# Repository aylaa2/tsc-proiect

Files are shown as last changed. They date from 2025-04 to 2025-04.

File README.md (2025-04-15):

# OpenBook – Open-Source E-Book Reader

OpenBook este un e-book reader open-source, low-cost, dezvoltat în cadrul proiectului TSC.  
Dispozitivul este construit pe baza microcontrolerului **ESP32-C6** și integrează funcționalități avansate de afișare, comunicație și consum redus de energie, fiind pregătit pentru producție în masă.

---

##  Diagrama Bloc

Diagrama bloc care ilustrează conexiunile dintre toate componentele:

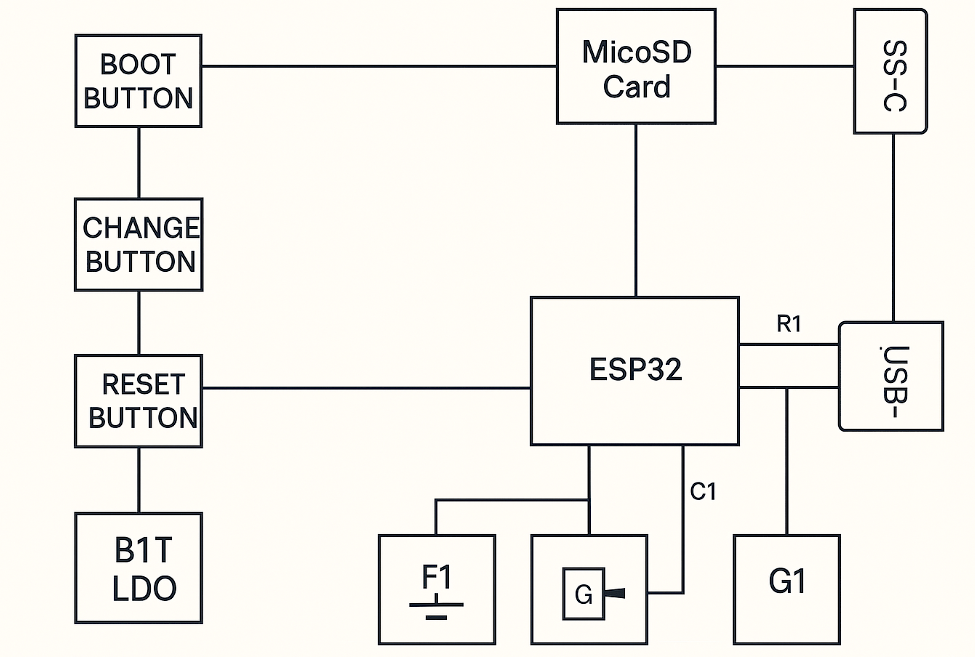
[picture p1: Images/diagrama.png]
Diagrama Bloc


---

##  BOM – Bill of Materials

# Bill of Materials (BOM)

| Package | Parts | Datasheet | 
|:---|:---|:---|
| ADAFRUIT_CHIP-LED0603 | CHG_LED | [Link](https://www.snapeda.com/parts/KP-1608SURCK/Kingbright/view-part/?ref=search&t=LED%200603) | 
| SJ | SJ1 | [Link](https://grabcad.com/library/solder-jumpers-1) |
| ESP32_WROVER_EAGLE-LTSPICE_R0402 | R1_PWRUSB, R1, R1_PINH1, R2-PINH, R2-PINH1, R5, R6, R7, R8, R9, R10, R_BOOT, R_CL1, R_RESET, R3, R1_PINH, R4, R_CHANGE, R_CAPACITOR, R2, R1_BAT, R2_BAT, R2_USB, R2_USB1 | [Link](https://componentsearchengine.com/part-view/R0402%201%25%20100%20K%20(RC0402FR-07100KL)/YAGEO) | 
| ESP32_WROVER_EAGLE-LTSPICE_C0402 | C1, C2, C4_USB, C6, C8, C9, C10, C_DELAY, EPD_C5, EPD_C1, EPD_C2, EPD_C6, EPD_C7, EPD_C8, EPD_C9, EPD_C10, EPD_C11, EPD_C12, C7, C5, C4, C1_BAT, C1_BAT1, C1_BAT2, C2_BAT, C5_USB | [Link](https://componentsearchengine.com/part-view/CC0402MRX5R5BB106/YAGEO) | 
| RCL_CT3528 | C3 | [Link](https://stud33302.autodesk360.com/g/shares/SH30dd5QT870c25f12fc6065d74bcaa3bf24) |
| 112ATAARR03ATTEND | J4 | [Link](Link) |
| ESP32_WROVER_SPARKFUN-DISCRETESEMI_SOT23-3 | Q1, Q2 | [Link](https://ro.mouser.com/ProductDetail/Microchip-Technology/MCP73831T-5ACI-OT?qs=hH%252BOa0VZEiAcgAcEkuamXg%3D%3D) |
| SOT95P280X125-5N | IC1 | [Link](https://componentsearchengine.com/part-view/BD5229G-TR/ROHM%20Semiconductor) |
| MYBUTTON | BOOT_BUTTON, CHANGE_BUTTON, RESET_BUTTON | [Link](https://industry.panasonic.com/global/en/products/control/switch/light-touch/number/evqpuj02k) |
| CAPCP3225X100N | C10_SUPERCAP | [Link](https://www.snapeda.com/parts/CPH3225A/Seiko+Instruments/view-part/?ref=eda) | 
| SOIC127P1032X265-16N | U3 | [Link](https://www.snapeda.com/parts/DS3231SN%23/Analog+Devices/view-part/?ref=eda) | 
| XCVR_ESP32-C6-WROOM-1-N8 | U2 | [Link](https://www.snapeda.com/parts/ESP32-C6-WROOM-1-N8/Espressif+Systems/view-part/?ref=eda) | 
| ESP32C6_VARISTOR_CT/CN1812 | PFMF.050.1 | [Link](Link) | 
| ESP32_WROVER_AVX---SD0805S020S1R0_AVX_SD0805S020S1R0_0 | D2, D7 | [Link](https://eu.mouser.com/ProductDetail/KYOCERA-AVX/SD0805S020S1R0?qs=jCA%252BPfw4LHbpkAoSnwrdjw%3D%3D) | 
| ESP32_WROVER_BME680_PSON80P300X300X100-8N | SENSOR2 | [Link](https://www.snapeda.com/parts/BME680/Bosch/view-part/?welcome=home) | 
| ESP32_WROVER_SPARKFUN-IC-POWER_SOT23-5 | U0 | [Link](Link) |
| FH34SRJ24S05SH99 | J1 | [Link](Link) | 
| SON50P200X200X80-9N | U4 | [Link](https://www.snapeda.com/parts/MAX17048G+T10/Analog+Devices/view-part/?ref=eda) | 
| SOD3716X135N | D3, D4, D5 | [Link](Lihttps://eu.mouser.com/ProductDetail/KYOCERA-AVX/SD0805S020S1R0?qs=jCA%252BPfw4LHbpkAoSnwrdjw%3D%3Dnk) | 
| DIOC1608X36N | D6, D8, D9, D10, D11, D12 | [Link](https://www.snapeda.com/parts/PGB1010603MR/Littelfuse/view-part/?ref=eda) | 
| JST04_1MM_RA | J3 | [Link](https://componentsearchengine.com/part-view/USB4110-GF-A/GCT%20(GLOBAL%20CONNECTOR%20TECHNOLOGY)) | 
| SAMACSYS_PARTS_USB4110GFA | J2 | [Link](https://componentsearchengine.com/part-view/USB4110-GF-A/GCT%20(GLOBAL%20CONNECTOR%20TECHNOLOGY)) | 
| SOT95P280X145-6N | D1 | [Link](https://www.snapeda.com/parts/USBLC6-2SC6Y/STMicroelectronics/view-part/?ref=eda) | 
| SON127P600X800X80-9N | U1 | [Link](https://www.snapeda.com/parts/W25Q512JVEIQ/Winbond+Electronics/view-part/?ref=eda) | 
| SOT95P280X120-5N | IC4 | [Link](https://www.snapeda.com/parts/W25Q512JVEIQ/Winbond+Electronics/view-part/?ref=eda) |

##  Descriere Hardware

OpenBook folosește următoarele module și componente:

- **ESP32-C6-WROOM-1-N8** – Microcontroller principal cu conectivitate WiFi 6, BLE și Zigbee.
- **W25Q512JVEIQ** – Memorie Flash SPI pentru stocarea datelor.
- **MAX17048** – Fuel Gauge pentru monitorizarea nivelului de încărcare a bateriei.
- **MCP73831** – Circuit de încărcare Li-Ion prin USB Type-C.
- **DS3231** – Ceas de timp real cu acuratețe ridicată.
- **BME680** – Senzor ambiental pentru calitatea aerului, temperatură și umiditate.
- **CPH3225A** – Supercapacitor pentru backup RTC.
- **USB4110-GF-A** – Conector USB Type-C pentru alimentare și comunicație.

**Specificații de comunicație și interfețe:**
- **I2C**: DS3231 (RTC), BME680 (senzor ambiental)
- **SPI**: W25Q512JVEIQ (memorie Flash externă)
- **I2C/SPI**: Ecran E-Paper
- **Fuel Gauge (MAX17048)**: comunicație prin I2C
- **USB**: Alimentare și încărcare prin MCP73831 + conector USB-C

**Calcul de consum de energie:**
- Dispozitivul intră în mod Deep Sleep ESP32 pentru a minimiza consumul (~20 µA).
- Fuel Gauge optimizează încărcarea/descărcarea bateriei pentru o autonomie maximă.

---

##  Pini ESP32-C6 

Mai jos este un rezumat al pinilor folosiți pe microcontroller, cu funcțiile și componenta asociată:

| GPIO  | Componentă | Funcție |
|---|---|---|
| EN | Buton Reset | Reset hardware |
| IO0 | RTC | INT_RTC (interupt RTC) |
| IO1 | RTC | 32KHz output |
| IO2 | SD Card | MISO |
| IO3 | E-paper Display | EPD_BUSY |
| IO4 | SD Card | SS_SD (chip select) |
| IO5 | E-paper Display | EPD_DC |
| IO6 | SPI Shared | SCK |
| IO7 | SPI Shared | MOSI |
| IO8 | GPIO | Utilizare generica |
| IO9 | Boot Button | Mod programare |
| IO10  | E-paper Display | EPD_CS |
| IO11  | NOR Flash | FLASH_CS |
| IO12  | USB Interface | USB_D- |
| IO13  | USB Interface | USB_D+ |
| IO15  | Buton Change | Detectare schimbare |
| IO16  | UART | TX (debug serial) |
| IO17  | UART | RX (debug serial) |
| IO18  | RTC | RTC_RST |
| IO19  | MAX17048 | I2C_PW (alimentare I2C) |
| IO20  | E-paper Display | EPD_3V3_C (power control) |
| IO21  | I2C Shared | SDA |
| IO22  | I2C Shared | SCL |
| IO23  | E-paper Display | EPD_RST |

---

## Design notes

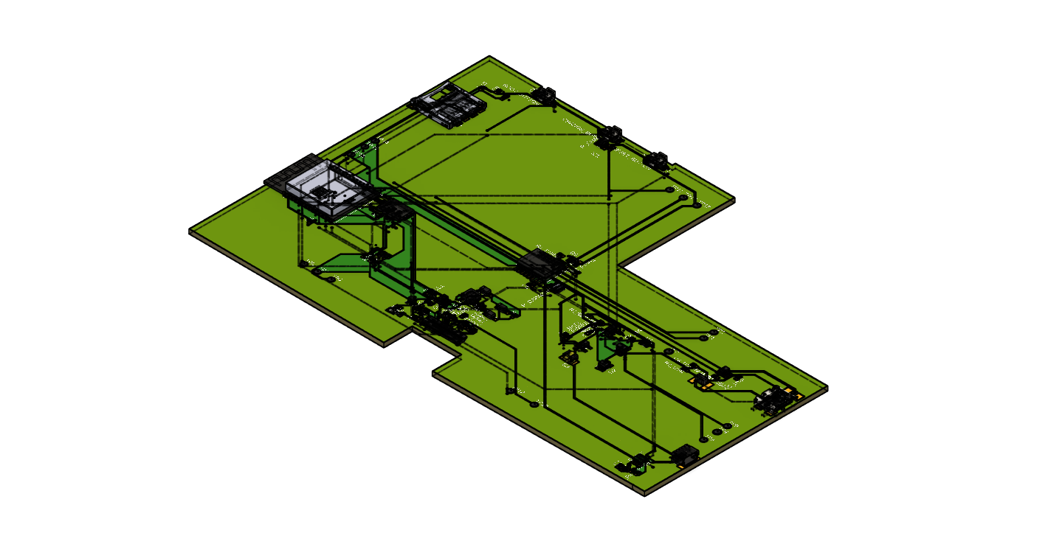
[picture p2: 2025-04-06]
Images/pleaca3d.png

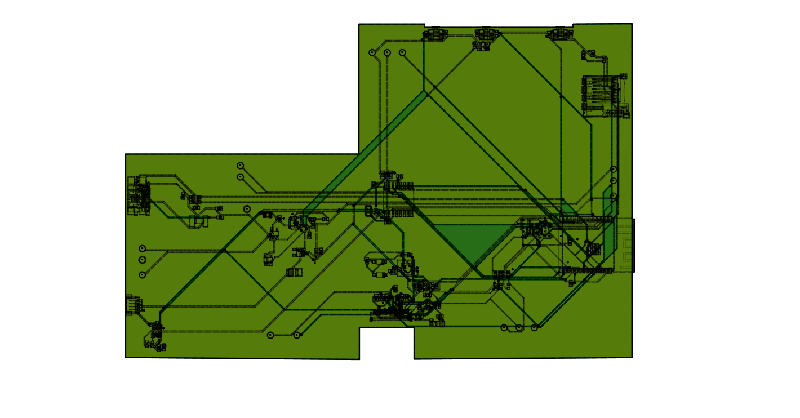
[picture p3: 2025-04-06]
Images/temabottom.png

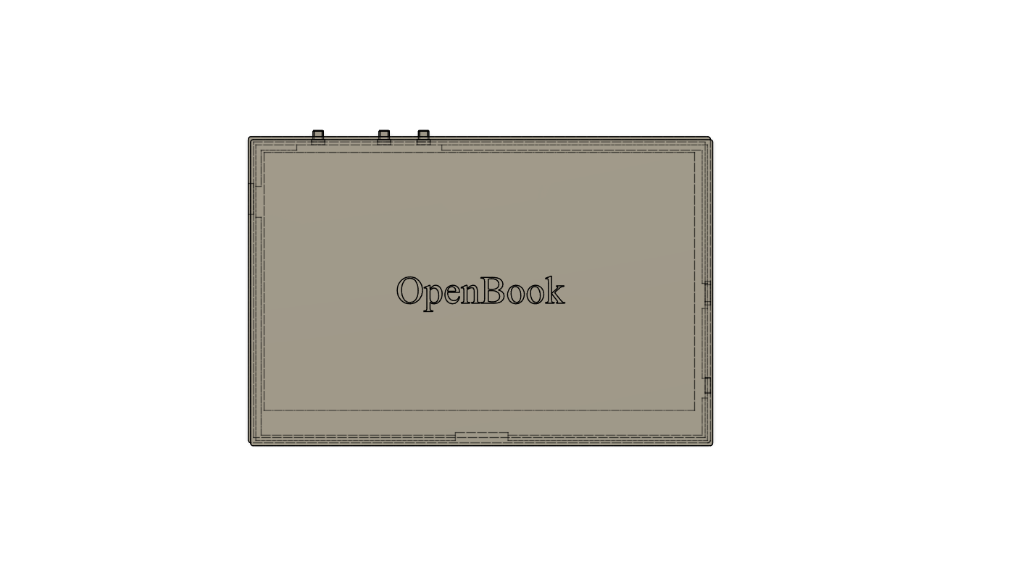
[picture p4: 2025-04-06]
Images/OpenBook Enclosure .png

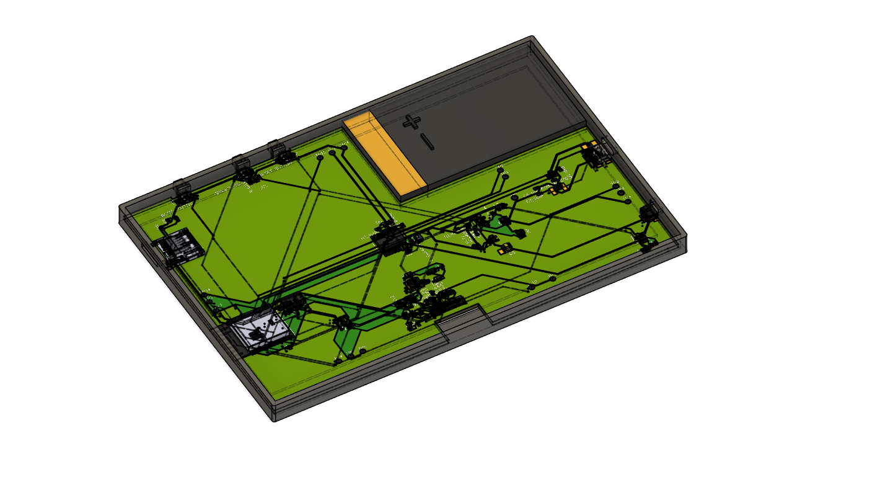
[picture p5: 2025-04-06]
Images/OpenBook Enclosuretop.png

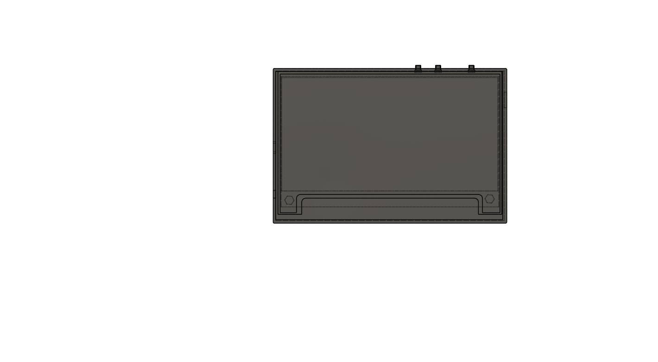
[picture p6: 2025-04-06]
Images/OpenBook Enclosure final v1.png

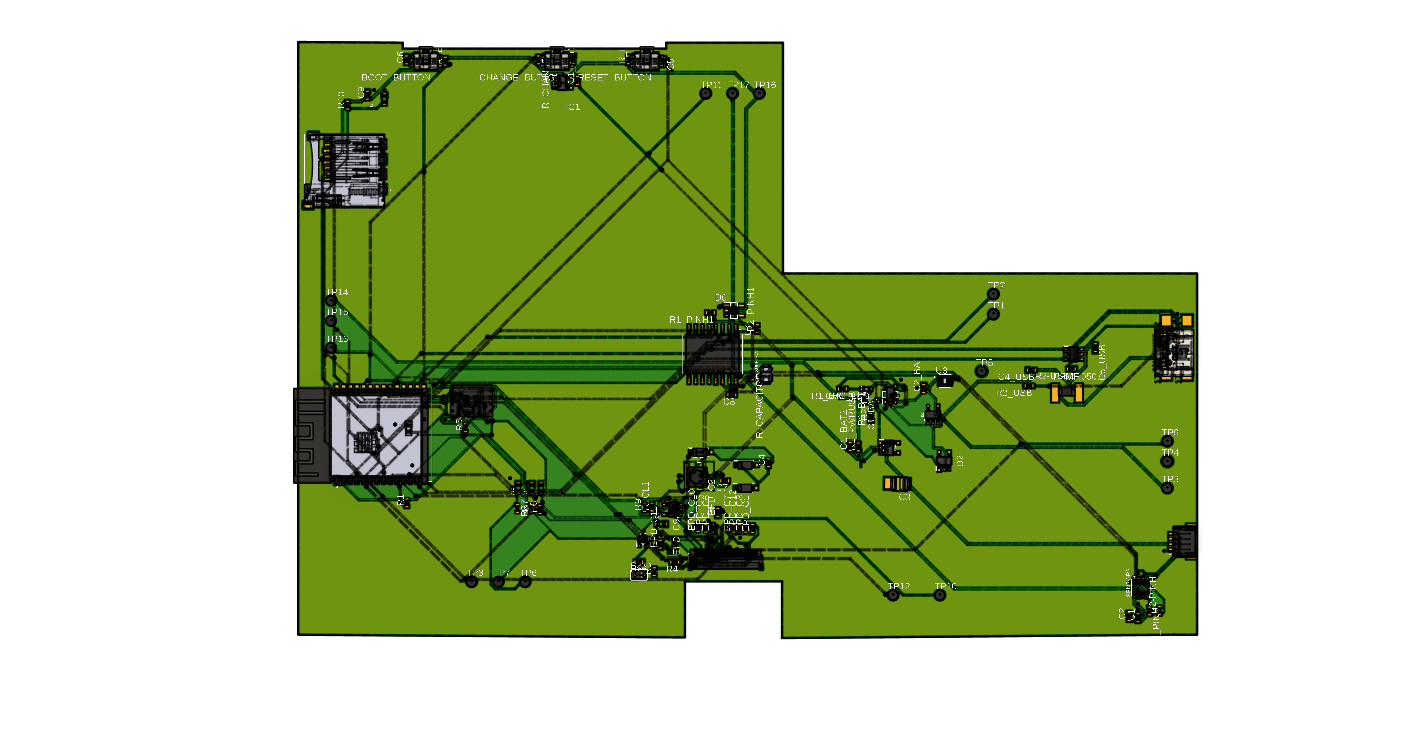
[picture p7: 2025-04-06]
Images/tema.png

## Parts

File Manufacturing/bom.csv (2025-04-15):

Qty | Value | Device | Package | Parts | Description | ARROW_PART_NUMBER | ARROW_PRICE-STOCK | AVAILABILITY | CENTROID_NOT_SPECIFIED | CHECK_PRICES | COPYRIGHT | DATASHEET | DESCRIPTION | DIGIKEY_DESCRIPTION | DIGIKEY_PART_NUMBER | HEIGHT | LEAD_FREE | MANUFACTURER_NAME | MANUFACTURER_PART_NUMBER | MF | MFR_NAME | MOUSER_PART_NUMBER | MOUSER_PRICE-STOCK | MOUSER_TESTING_PART_NUMBER | MOUSER_TESTING_PRICE-STOCK | MP | MPN | PACKAGE | POPULARITY | PREFIX | PRICE | PROD_ID | PURCHASE-URL | ROHS | SNAPEDA_LINK | SPICEMODEL | SPICEPREFIX | TEMPERATURE_RANGE_HIGH | TEMPERATURE_RANGE_LOW | TP_SIGNAL_NAME | VALUE
1 |  | ADAFRUIT_LEDCHIP-LED0603 | ADAFRUIT_CHIP-LED0603 | CHG_LED | LED
1 |  | SJ | SJ | SJ1 | SMD solder JUMPER |  |  |  |  |  |  |  |  |  |  |  |  |  |  |  |  |  |  |  |  |  |  |  | 3
1 | 0.47 | ESP32_WROVER_EAGLE-LTSPICE_RR0402 | ESP32_WROVER_EAGLE-LTSPICE_R0402 | R3 | RESISTOR, European symbol |  |  |  |  |  |  |  |  |  |  |  |  |  |  |  |  |  |  |  |  |  |  |  |  |  |  |  |  |  |  | NONE | R
1 | 100K | ESP32_WROVER_EAGLE-LTSPICE_RR0402 | ESP32_WROVER_EAGLE-LTSPICE_R0402 | R1_PWRUSB | RESISTOR, European symbol |  |  |  |  |  |  |  |  |  |  |  |  |  |  |  |  |  |  |  |  |  |  |  |  |  |  |  |  |  |  | NONE | R
6 | 100nF | EAGLE-LTSPICE_CC0402 | ESP32_WROVER_EAGLE-LTSPICE_C0402 | C1, C2, C6, C8, C9, C10 | CAPACITOR, European symbol |  |  |  |  |  |  |  |  |  |  |  |  |  |  |  |  |  |  |  |  |  |  |  |  |  |  |  |  |  |  | NONE | C
1 | 100nF | ESP32_WROVER_EAGLE-LTSPICE_CC0402 | ESP32_WROVER_EAGLE-LTSPICE_C0402 | C4_USB | CAPACITOR, European symbol |  |  |  |  |  |  |  |  |  |  |  |  |  |  |  |  |  |  |  |  |  |  |  |  |  |  |  |  |  |  | NONE | C
1 | 100uF TANT | RCL_CPOL-EUCT3528 | RCL_CT3528 | C3 | POLARIZED CAPACITOR, European symbol |  |  |  |  |  |  |  |  |  |  |  |  |  |  |  |  |  |  |  |  |  |  |  | 0 |  |  |  |  |  |  |  | C
13 | 10K | ESP32_WROVER_EAGLE-LTSPICE_RR0402 | ESP32_WROVER_EAGLE-LTSPICE_R0402 | R1, R1_PINH, R1_PINH1, R2-PINH, R2_PINH1, R4, R5, R6, R7, R8, R9, R10, R_CL1 | RESISTOR, European symbol |  |  |  |  |  |  |  |  |  |  |  |  |  |  |  |  |  |  |  |  |  |  |  |  |  |  |  |  |  |  | NONE | R
3 | 10k | ESP32_WROVER_EAGLE-LTSPICE_RR0402 | ESP32_WROVER_EAGLE-LTSPICE_R0402 | R_BOOT, R_CHANGE, R_RESET | RESISTOR, European symbol |  |  |  |  |  |  |  |  |  |  |  |  |  |  |  |  |  |  |  |  |  |  |  |  |  |  |  |  |  |  | NONE | R
1 | 10uF | EAGLE-LTSPICE_CC0402 | ESP32_WROVER_EAGLE-LTSPICE_C0402 | C7 | CAPACITOR, European symbol |  |  |  |  |  |  |  |  |  |  |  |  |  |  |  |  |  |  |  |  |  |  |  |  |  |  |  |  |  |  | NONE | C
1 | 112A-TAAR-R03_ATTEND | 112A-TAAR-R03_ATTEND | 112ATAARR03ATTEND | J2 | Micro SD Card Socket, Push-Push Type, Top Mount, SMT, H=1.83mm, 10u |  |  |  |  |  |  |  | Micro SD Card Socket | Push-Push Type | Top Mount | SMT | H=1.83mm | 10u |  |  | 1.9mm |  | ATTEND | 112A-TAAR-R03 ATTEND
1 | 15 | ESP32_WROVER_EAGLE-LTSPICE_RR0402 | ESP32_WROVER_EAGLE-LTSPICE_R0402 | R_CAPACITOR | RESISTOR, European symbol |  |  |  |  |  |  |  |  |  |  |  |  |  |  |  |  |  |  |  |  |  |  |  |  |  |  |  |  |  |  | NONE | R
1 | 1uF | EAGLE-LTSPICE_CC0402 | ESP32_WROVER_EAGLE-LTSPICE_C0402 | C5 | CAPACITOR, European symbol |  |  |  |  |  |  |  |  |  |  |  |  |  |  |  |  |  |  |  |  |  |  |  |  |  |  |  |  |  |  | NONE | C
10 | 1uF/50V | EAGLE-LTSPICE_CC0402 | ESP32_WROVER_EAGLE-LTSPICE_C0402 | EPD_C1, EPD_C2, EPD_C5, EPD_C6, EPD_C7, EPD_C8, EPD_C9, EPD_C10, EPD_C11, EPD_C12 | CAPACITOR, European symbol |  |  |  |  |  |  |  |  |  |  |  |  |  |  |  |  |  |  |  |  |  |  |  |  |  |  |  |  |  |  | NONE | C
1 | 2.2 | ESP32_WROVER_EAGLE-LTSPICE_RR0402 | ESP32_WROVER_EAGLE-LTSPICE_R0402 | R2 | RESISTOR, European symbol |  |  |  |  |  |  |  |  |  |  |  |  |  |  |  |  |  |  |  |  |  |  |  |  |  |  |  |  |  |  | NONE | R
1 | 200 | ESP32_WROVER_EAGLE-LTSPICE_RR0402 | ESP32_WROVER_EAGLE-LTSPICE_R0402 | R1_BAT | RESISTOR, European symbol |  |  |  |  |  |  |  |  |  |  |  |  |  |  |  |  |  |  |  |  |  |  |  |  |  |  |  |  |  |  | NONE | R
2 | 20V/4.2A/52mO/1.4W | ESP32_WROVER_SPARKFUN-DISCRETESEMI_MOSFET_PCH-DMG2305UX-7 | ESP32_WROVER_SPARKFUN-IC-POWER_SOT23-5 | Q1, Q2 | P-channel MOSFETs |  |  |  |  |  |  |  |  |  |  |  |  |  |  |  |  |  |  |  |  |  |  |  |  |  |  | TRAN-14388 |  |  |  |  |  |  |  |  | 20V/4.2A/52mO/1.4W
1 | 2K | ESP32_WROVER_EAGLE-LTSPICE_RR0402 | ESP32_WROVER_EAGLE-LTSPICE_R0402 | R2_BAT | RESISTOR, European symbol |  |  |  |  |  |  |  |  |  |  |  |  |  |  |  |  |  |  |  |  |  |  |  |  |  |  |  |  |  |  | NONE | R
1 | 4,7uF | EAGLE-LTSPICE_CC0402 | ESP32_WROVER_EAGLE-LTSPICE_C0402 | C1_BAT2 | CAPACITOR, European symbol |  |  |  |  |  |  |  |  |  |  |  |  |  |  |  |  |  |  |  |  |  |  |  |  |  |  |  |  |  |  | NONE | C
2 | 4.7uF | EAGLE-LTSPICE_CC0402 | ESP32_WROVER_EAGLE-LTSPICE_C0402 | C1_BAT, C1_BAT1 | CAPACITOR, European symbol |  |  |  |  |  |  |  |  |  |  |  |  |  |  |  |  |  |  |  |  |  |  |  |  |  |  |  |  |  |  | NONE | C
2 | 4.7uF | ESP32_WROVER_EAGLE-LTSPICE_CC0402 | ESP32_WROVER_EAGLE-LTSPICE_C0402 | C2_BAT, C5_USB | CAPACITOR, European symbol |  |  |  |  |  |  |  |  |  |  |  |  |  |  |  |  |  |  |  |  |  |  |  |  |  |  |  |  |  |  | NONE | C
1 | 4.7uF/25V | EAGLE-LTSPICE_CC0402 | ESP32_WROVER_EAGLE-LTSPICE_C0402 | C4 | CAPACITOR, European symbol |  |  |  |  |  |  |  |  |  |  |  |  |  |  |  |  |  |  |  |  |  |  |  |  |  |  |  |  |  |  | NONE | C
1 | 5K1 | ESP32_WROVER_EAGLE-LTSPICE_RR0402 | ESP32_WROVER_EAGLE-LTSPICE_R0402 | R2_USB | RESISTOR, European symbol |  |  |  |  |  |  |  |  |  |  |  |  |  |  |  |  |  |  |  |  |  |  |  |  |  |  |  |  |  |  | NONE | R
1 | 5k1 | ESP32_WROVER_EAGLE-LTSPICE_RR0402 | ESP32_WROVER_EAGLE-LTSPICE_R0402 | R2-USB1 | RESISTOR, European symbol |  |  |  |  |  |  |  |  |  |  |  |  |  |  |  |  |  |  |  |  |  |  |  |  |  |  |  |  |  |  | NONE | R
1 | 68uH | 744043680IND_4828-WE-TPC_WRE | IND_4828-WE-TPC_WRE | L1 |  |  |  |  |  |  | Copyright (C) 2024 Ultra Librarian. All rights reserved. |  |  |  |  |  |  |  | 744043680 |  | Wurth Electronics
1 | BD5229G-TR | BD5229G-TR | SOT95P280X120-5N | IC2 | Voltage Detector with Adjustable Delay Time: CMOS processes are utilized to develop high precision, low current consumption CMOS reset ICs that allow arbitrary setting of the delay time. The extensive lineup includes both Nch Open Drain and CMOS output types in a wide range of detection voltages (from 2.3V to 6.0V, in 0.1V steps), enabling selection of the ideal solution based on customer requirements. In addition, the entire series is of course both lead-free and RoHS-compliant. |  |  |  |  |  |  |  | Voltage Detector with Adjustable Delay Time: CMOS processes are utilized to develop high precision | low current consumption CMOS reset ICs that allow arbitrary setting of the delay time. The extensive lineup includes both Nch Open Drain and CMOS output types in a wide range of detection voltages (from 2.3V to 6.0V | in 0.1V steps) | enabling selection of the ideal solution based on customer requirements. In addition | the entire series is of course both lead-free and RoHS-compliant. |  |  | 1.25mm |  | ROHM Semiconductor | BD5229G-TR |  |  | 755-BD5229G-TR | https://www.mouser.co.uk/ProductDetail/ROHM-Semiconductor/BD5229G-TR?qs=4kLU8WoGk0vvnhrrYwdszw%3D%3D
3 | BUTTON_CUSYOMV1 | BUTTON_CUSYOMV1 | MYBUTTON | BOOT_BUTTON, CHANGE_BUTTON, RESET_BUTTON
1 | CPH3225A | CPH3225A | CAPCP3225X100N | C10_SUPERCAP | Cap 0.011F 3.3V 1210 Flat Check availability |  |  | Not in stock |  | https://www.snapeda.com/parts/CPH3225A/Seiko+Instruments/view-part/?ref=eda |  |  | 11 mF (EDLC) Supercapacitor 3.3 V 1210 (3225 Metric) - - |  |  |  |  |  |  | Seiko Instruments |  |  |  |  |  | CPH3225A |  | 1210 Seiko |  |  | None |  | https://www.snapeda.com/api/url_track_click_mouser/?unipart_id=562593&manufacturer=Seiko Instruments&part_name=CPH3225A&search_term=None |  | https://www.snapeda.com/parts/CPH3225A/Seiko+Instruments/view-part/?ref=snap
1 | DS3231SN# | DS3231SN# | SOIC127P1032X265-16N | U4 | Real Time Clock Serial 16-Pin SOIC W T/R Check availability |  |  | In Stock |  | https://www.snapeda.com/parts/DS3231SN%23/Analog+Devices/view-part/?ref=eda |  |  | Extremely Accurate I²C-Integrated RTC/TCXO/Crystal |  |  |  |  |  |  | Analog Devices |  |  |  |  |  | DS3231SN# |  | SOIC-16 Maxim |  |  | None |  | https://www.snapeda.com/api/url_track_click_mouser/?unipart_id=99048&manufacturer=Analog Devices&part_name=DS3231SN#&search_term=None |  | https://www.snapeda.com/parts/DS3231SN%23/Analog+Devices/view-part/?ref=snap
1 | ESP32-C6-WROOM-1-N8 | ESP32-C6-WROOM-1-N8 | XCVR_ESP32-C6-WROOM-1-N8 | U2 | Check availability |  |  | In Stock |  | https://www.snapeda.com/parts/ESP32-C6-WROOM-1-N8/Espressif+Systems/view-part/?ref=eda |  |  | Multiprotocol Modules ESP32-C6 module | Wi-Fi 6 in 2.4 GHz band | Bluetooth 5 | Zigbee 3.0 and Thread. ESP34-WROOM Compatible - ENGINEERING SAMPLE |  |  |  |  |  |  | Espressif Systems |  |  |  |  |  | ESP32-C6-WROOM-1-N8 |  | None |  |  | None |  |  |  | https://www.snapeda.com/parts/ESP32-C6-WROOM-1-N8/Espressif+Systems/view-part/?ref=snap
1 | ESP32C6_VARISTORCN1812 | ESP32C6_VARISTORCN1812 | ESP32C6_VARISTOR_CT/CN1812 | PFMF.050.1 | VARISTOR |  |  |  |  |  |  |  |  |  |  |  |  |  |  |  |  |  |  |  |  |  |  |  | 0
2 | ESP32_WROVER_AVX---SD0805S020S1R0_AVX_SD0805S020S1R0_0_0AVX_SD0805S020S1R0_0_0 | ESP32_WROVER_AVX---SD0805S020S1R0_AVX_SD0805S020S1R0_0_0AVX_SD0805S020S1R0_0_0 | SOT95P280X120-5N | D2, D6 | Schottky Barrier Rectifier Diode |  |  |  | No |  |  | http://datasheets.avx.com/schottky.pdf |  | DIODE SCHOTTKY 20V 1A 0805 | 478-7800-1-ND |  | yes |  |  | AVX |  | 581-SD0805S020S1R0 |  |  |  |  |  | 0805 (2012 metric) |  | D |  |  |  | yes |  |  |  | +125°C | -55°C
1 | ESP32_WROVER_BME680_BME680 | ESP32_WROVER_BME680_BME680 | ESP32_WROVER_BME680_PSON80P300X300X100-8N | SENSOR2 | Integrated Environmental Unit |  |  | Unavailable |  |  |  |  | Integrated Environmental Unit |  |  |  |  |  |  | Bosch Sensortec |  |  |  |  |  | BME680 |  | LGA-8 Bosch Tools |  |  | None
1 | ESP32_WROVER_SPARKFUN-IC-POWER_MCP73831 | ESP32_WROVER_SPARKFUN-IC-POWER_MCP73831 | SOT95P280X125-5N | U1 | MCP73831T Li-Ion, Li-Pol Controller |  |  |  |  |  |  |  |  |  |  |  |  |  |  |  |  |  |  |  |  |  |  |  |  |  |  | IC-09995
1 | FH34SRJ-24S-0.5SH_99_ | FH34SRJ-24S-0.5SH_99_ | FH34SRJ24S05SH99 | J3 | (0.50mm) Surface Mount, Right Angle |  |  |  |  |  |  |  | 24 Position FFC | FPC Connector Contacts | (0.50mm) Surface Mount | Right Angle |  |  | 1.1mm |  | Hirose | FH34SRJ-24S-0.5SH(99) |  |  | 798-FH34SRJ24S05SH99 | https://www.mouser.co.uk/ProductDetail/Hirose-Connector/FH34SRJ-24S-0.5SH99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
1 | MAX17048G+T10 | MAX17048G+T10 | SON50P200X200X80-9N | U3 | Check availability |  |  | In Stock |  | https://www.snapeda.com/parts/MAX17048G+T10/Analog+Devices/view-part/?ref=eda |  |  | 3µA 1-Cell/2-Cell Fuel Gauge with ModelGauge |  |  |  |  |  |  | Analog Devices |  |  |  |  |  | MAX17048G+T10 |  | TDFN-8 Maxim |  |  | None |  | https://www.snapeda.com/api/url_track_click_mouser/?unipart_id=329239&manufacturer=Analog Devices&part_name=MAX17048G+T10&search_term=None |  | https://www.snapeda.com/parts/MAX17048G+T10/Analog+Devices/view-part/?ref=snap
3 | MBR0530 | MBR0530 | SOD3716X135N | D3, D4, D5 | ON SEMICONDUCTOR - MBR0530 - DIODE, SCHOTTKY, 0.5A, 30V, SOD-123 |  |  | In Stock |  | https://www.snapeda.com/parts/MBR0530/Onsemi/view-part/?ref=eda |  |  | Diode Schottky 30 V 500mA Surface Mount SOD-123 |  |  |  |  |  |  | ON Semiconductor |  |  |  |  |  | MBR0530 |  | SOD-123-2 ON Semiconductor |  |  | None |  | https://www.snapeda.com/api/url_track_click_mouser/?unipart_id=179458&manufacturer=ON Semiconductor&part_name=MBR0530&search_term=None |  | https://www.snapeda.com/parts/MBR0530/Onsemi/view-part/?ref=snap
6 | PGB1010603MR | PGB1010603MR | DIOC1608X36N | D7, D8, D9, D10, D11, D12 | Check availability |  |  | In Stock |  | https://www.snapeda.com/parts/PGB1010603MR/Littelfuse/view-part/?ref=eda |  |  | 150V (Typ) Clamp - Ipp Tvs Diode Surface Mount 0603 (1608 Metric) |  |  |  |  |  |  | Littelfuse Inc. |  |  |  |  |  | PGB1010603MR |  | 0603 Littelfuse Inc. |  |  | None |  | https://www.snapeda.com/api/url_track_click_mouser/?unipart_id=5659453&manufacturer=Littelfuse Inc.&part_name=PGB1010603MR&search_term=None |  | https://www.snapeda.com/parts/PGB1010603MR/Littelfuse/view-part/?ref=snap
1 | QWIIC_RIGHT_ANGLE | QWIIC_CONNECTORJS-1MM | JST04_1MM_RA | J4 | SparkFun I2C Standard Qwiic Connector |  |  |  |  |  |  |  |  |  |  |  |  |  |  |  |  |  |  |  |  |  |  |  |  |  |  | CONN-13694 |  |  |  |  |  |  |  |  | QWIIC_RIGHT_ANGLE
1 | SAMACSYS_PARTS_USB4110-GF-A | SAMACSYS_PARTS_USB4110-GF-A | SAMACSYS_PARTS_USB4110GFA | J1 | CONN USB 2.0 TYPE-C R/A SMT |  |  |  |  |  |  |  | CONN USB 2.0 TYPE-C R/A SMT |  |  | 3.26mm |  | GCT (GLOBAL CONNECTOR TECHNOLOGY) | USB4110-GF-A |  |  | 640-USB4110-GF-A | https://www.mouser.co.uk/ProductDetail/GCT/USB4110-GF-A?qs=KUoIvG%2F9IlYiZvIXQjyJeA%3D%3D
1 | SI1308EDL-T1-GE3 | SI1308EDL-T1-GE3 | SOT65P210X110-3N | Q3 | MOSFET N-Ch 30V 1.5A TrenchFET SC70 Vishay Si1308EDL-T1-GE3 N-channel MOSFET Transistor, 1.5 A, 30 V, 3-Pin SC-70 |  |  | In Stock |  | https://www.snapeda.com/parts/SI1308EDL-T1-GE3/Vishay+Siliconix/view-part/?ref=eda |  |  | Si1308EDL-T1-GE3 N-channel MOSFET Transistor | 1.5 A | 30 V | 3-Pin SC-70 | Siliconix / Vishay SI1308EDL-T1-GE3 |  |  |  |  |  |  | Vishay Siliconix |  |  |  |  |  | SI1308EDL-T1-GE3 |  | SOT-323 Vishay Semiconductor |  |  | None |  | https://www.snapeda.com/api/url_track_click_mouser/?unipart_id=274603&manufacturer=Vishay Siliconix&part_name=SI1308EDL-T1-GE3&search_term=None |  | https://www.snapeda.com/parts/SI1308EDL-T1-GE3/Vishay+Siliconix/view-part/?ref=snap
17 | TPTP20R | TPTP20R | TP20R | TP1, TP2, TP3, TP4, TP5, TP6, TP7, TP8, TP9, TP10, TP11, TP12, TP13, TP14, TP15, TP16, TP17 | Test pad |  |  |  |  |  |  |  |  |  |  |  |  |  |  |  |  |  |  |  |  |  |  |  | 2
1 | USBLC6-2SC6Y | USBLC6-2SC6Y | SOT95P280X145-6N | D1 | Low Cap. ESD Protection Auto SOT-23-6 STMicroelectronics USBLC6-2SC6Y, Dual Uni-Directional TVS Diode Array, 6-Pin SOT-23 |  |  | In Stock |  | https://www.snapeda.com/parts/USBLC6-2SC6Y/STMicroelectronics/view-part/?ref=eda |  |  | 17V Clamp 5A (8/20µs) Ipp Tvs Diode Surface Mount SOT-23-6 |  |  |  |  |  |  | STMicroelectronics |  |  |  |  |  | USBLC6-2SC6Y |  | SOT-23-6 STMicroelectronics |  |  | None |  |  |  | https://www.snapeda.com/parts/USBLC6-2SC6Y/STMicroelectronics/view-part/?ref=snap
1 | W25Q512JVEIQ | W25Q512JVEIQ | SON50P200X200X80-9N | U5 | Check availability |  |  | In Stock |  | https://www.snapeda.com/parts/W25Q512JVEIQ/Winbond+Electronics/view-part/?ref=eda |  |  | FLASH - NOR Memory IC 512Mb (64M x 8) SPI - Quad I/O 133 MHz 8-WSON (8x6) |  |  |  |  |  |  | Winbond Electronics |  |  |  |  |  | W25Q512JVEIQ |  | Package |  |  | None |  |  |  | https://www.snapeda.com/parts/W25Q512JVEIQ/Winbond+Electronics/view-part/?ref=snap
1 | XC6220A331MR-G | XC6220A331MR-G | SOT95P280X120-5N | IC1 | LDO Voltage Regulators |  |  |  |  |  |  |  | LDO Voltage Regulators |  |  | 1.2mm |  | Torex | XC6220A331MR-G |  |  | 865-XC6220A331MR-G | https://www.mouser.co.uk/ProductDetail/Torex-Semiconductor/XC6220A331MR-G?qs=AsjdqWjXhJ8ZSWznL1J0gg%3D%3D

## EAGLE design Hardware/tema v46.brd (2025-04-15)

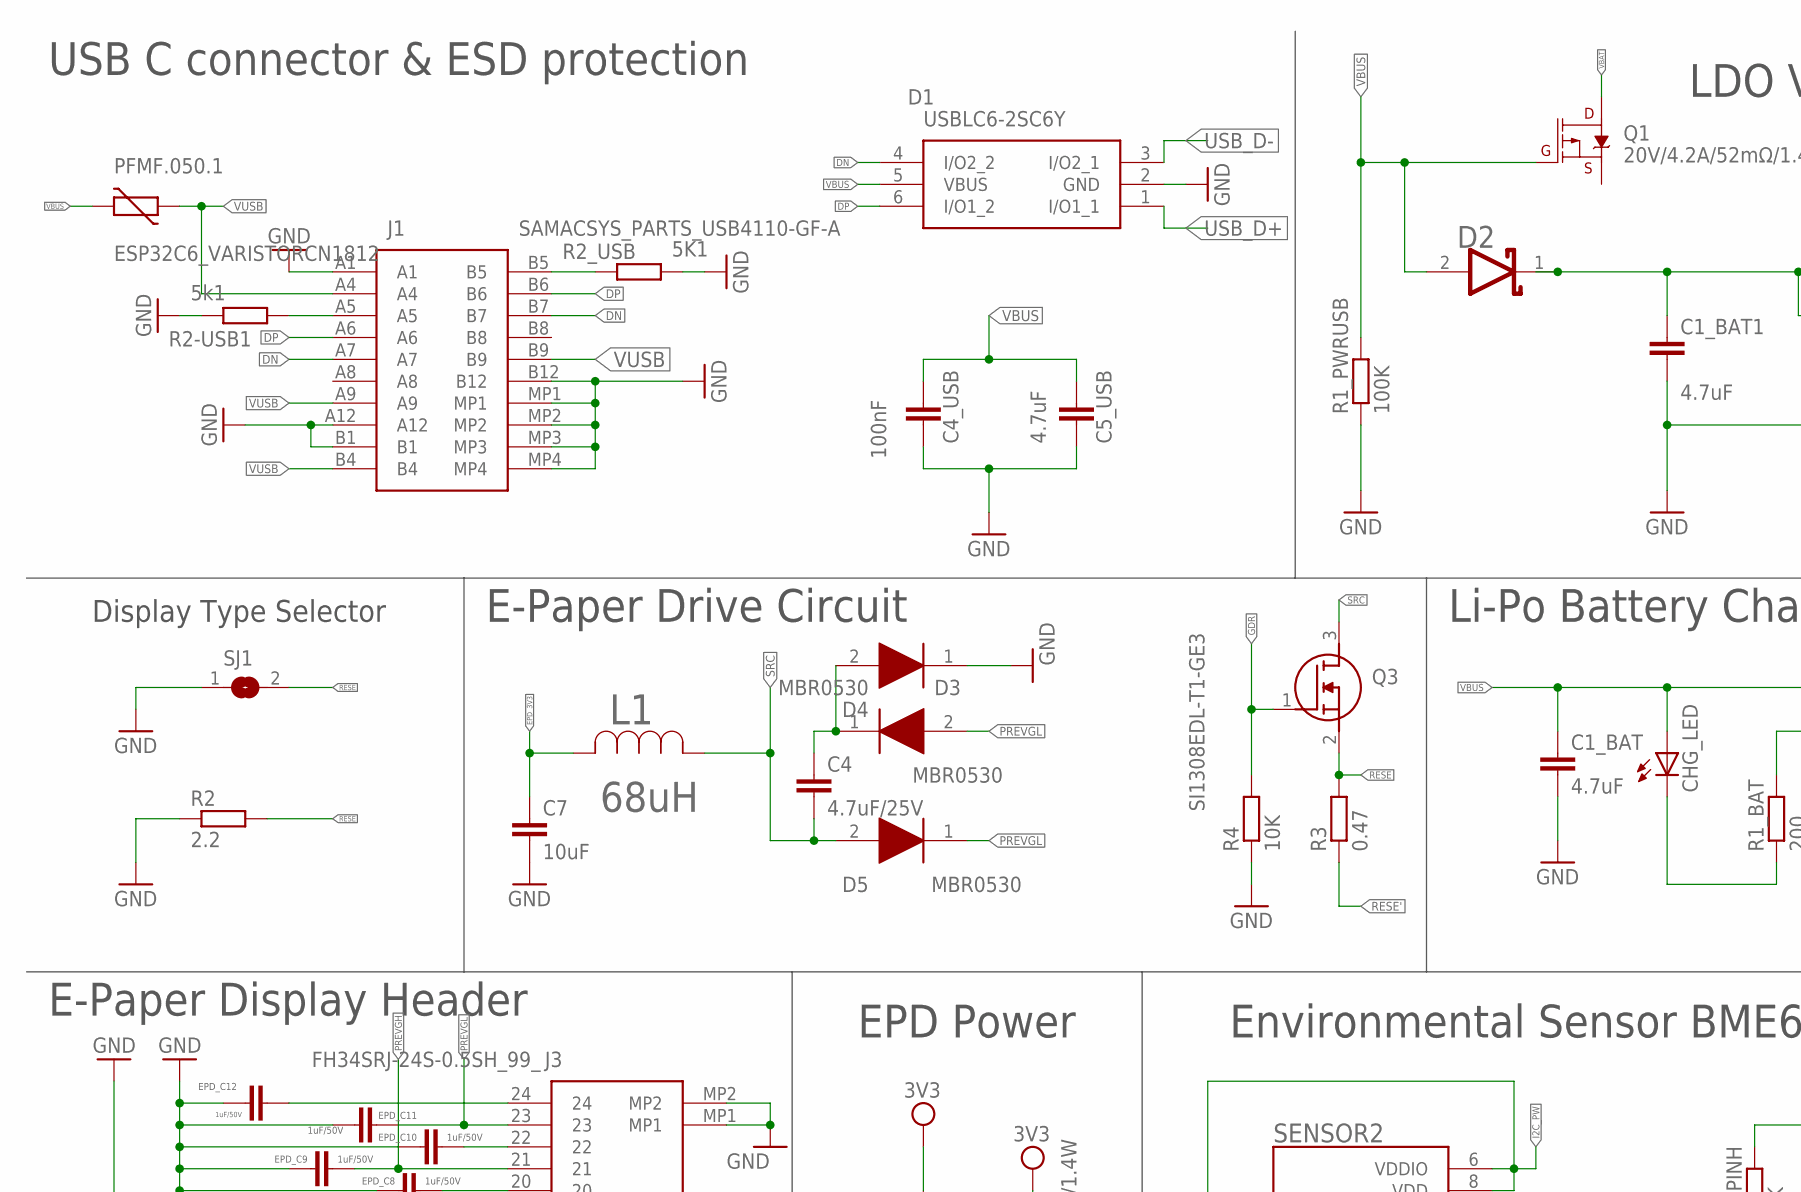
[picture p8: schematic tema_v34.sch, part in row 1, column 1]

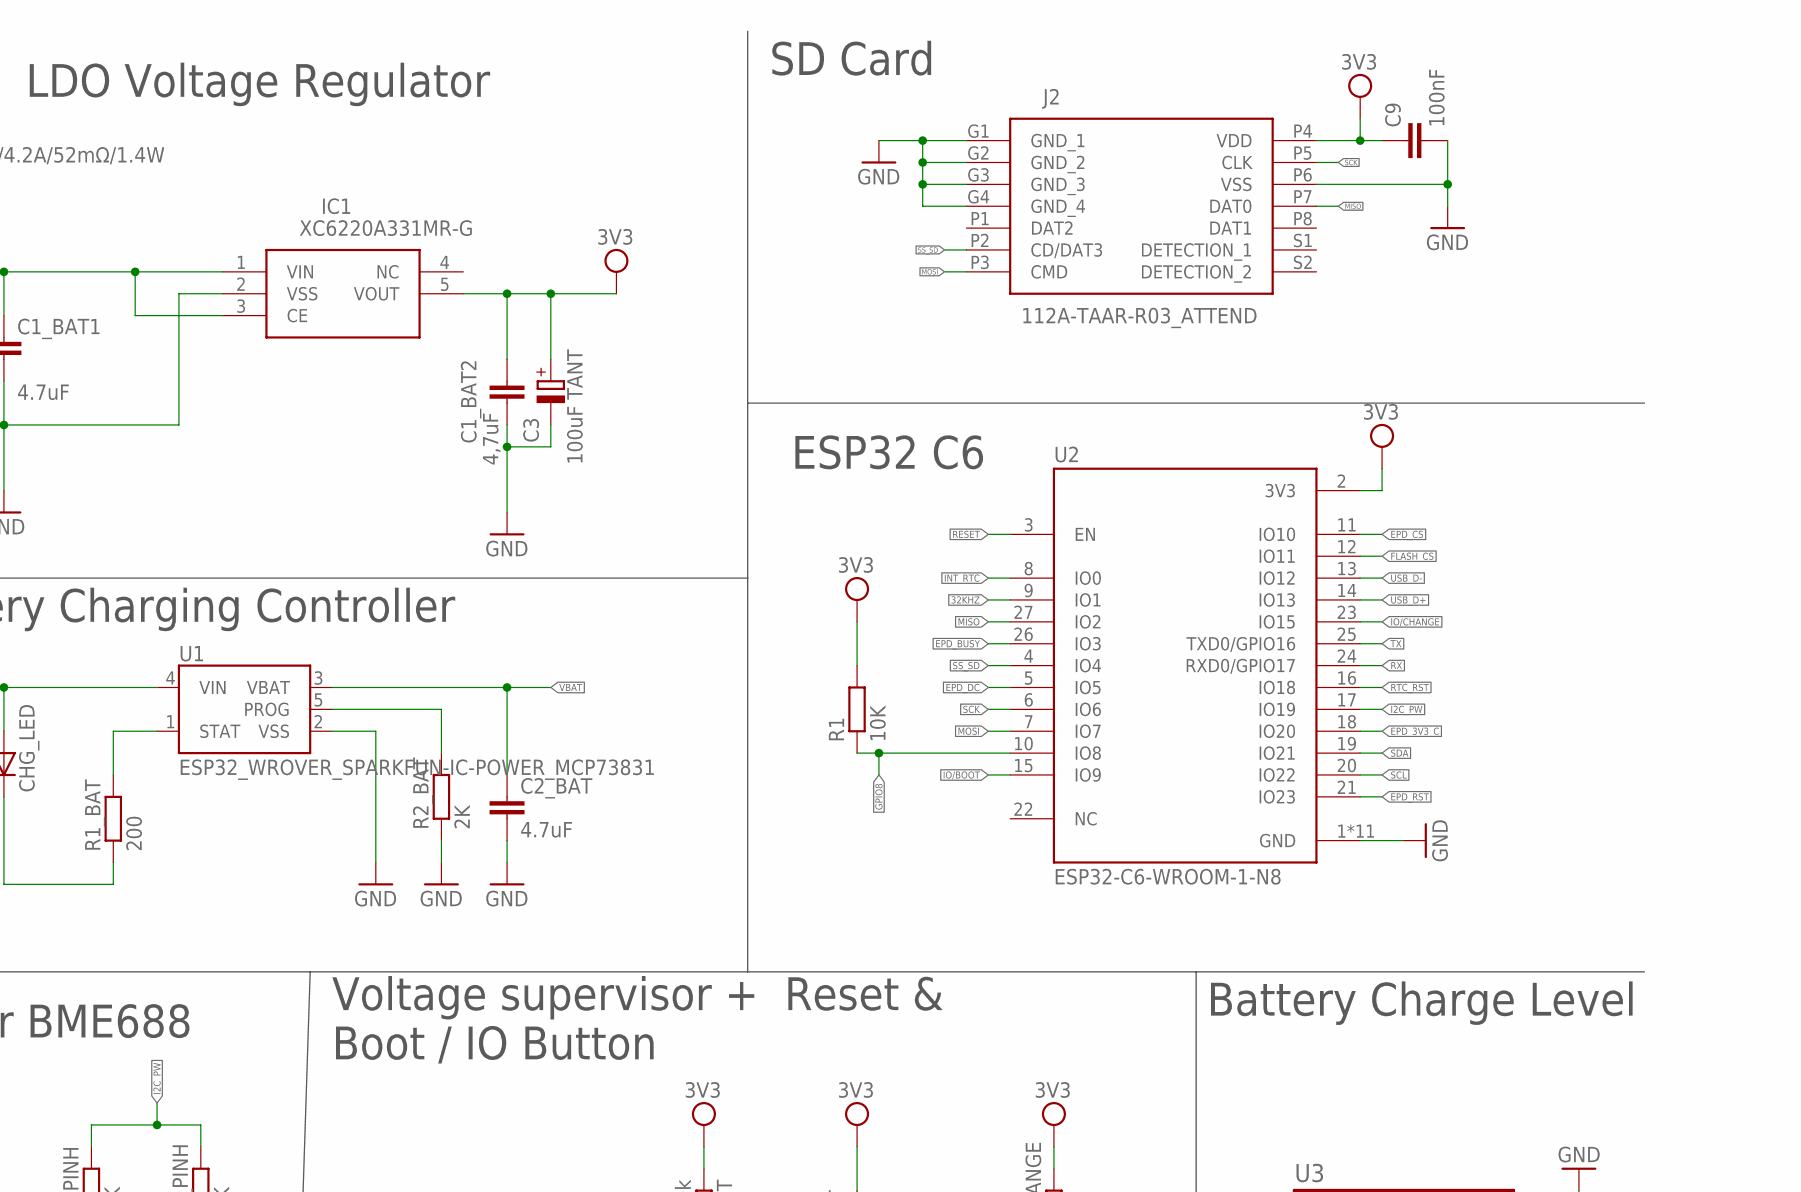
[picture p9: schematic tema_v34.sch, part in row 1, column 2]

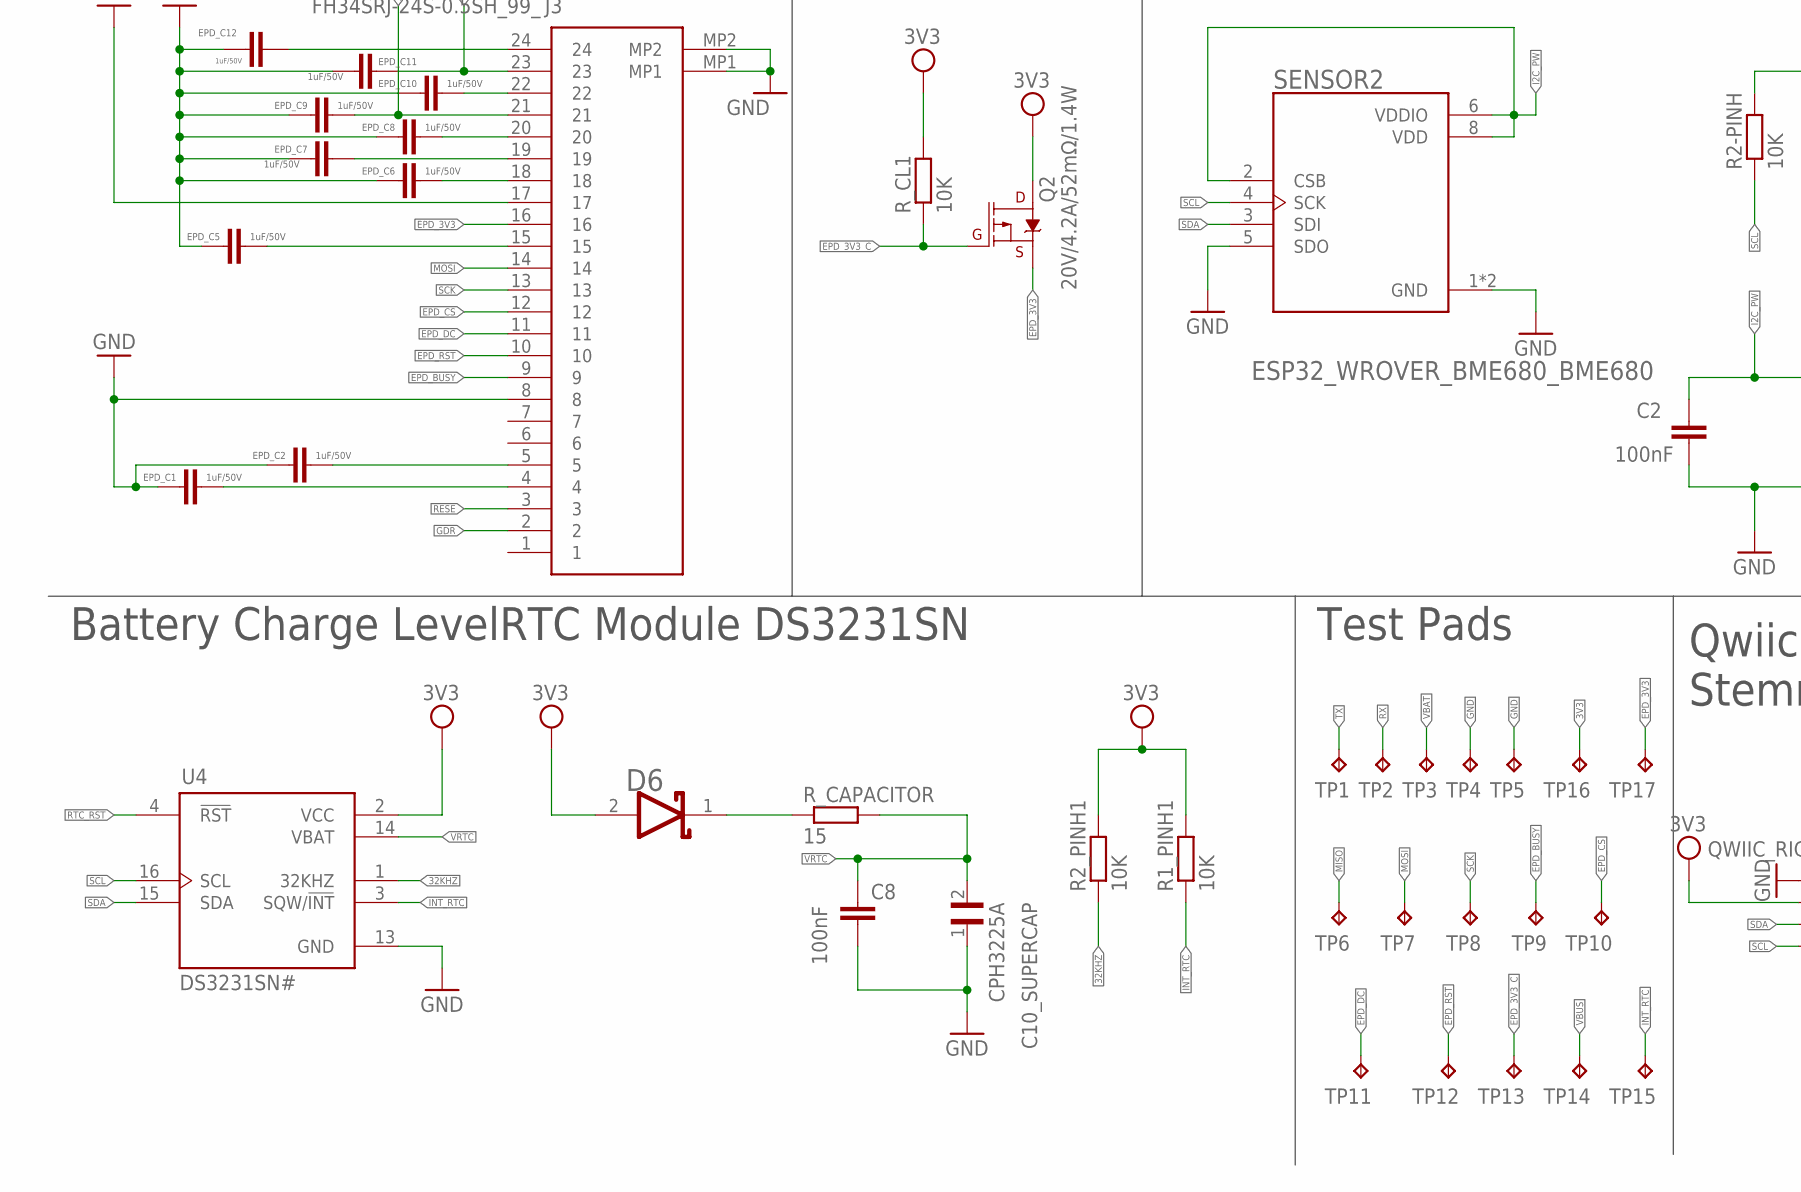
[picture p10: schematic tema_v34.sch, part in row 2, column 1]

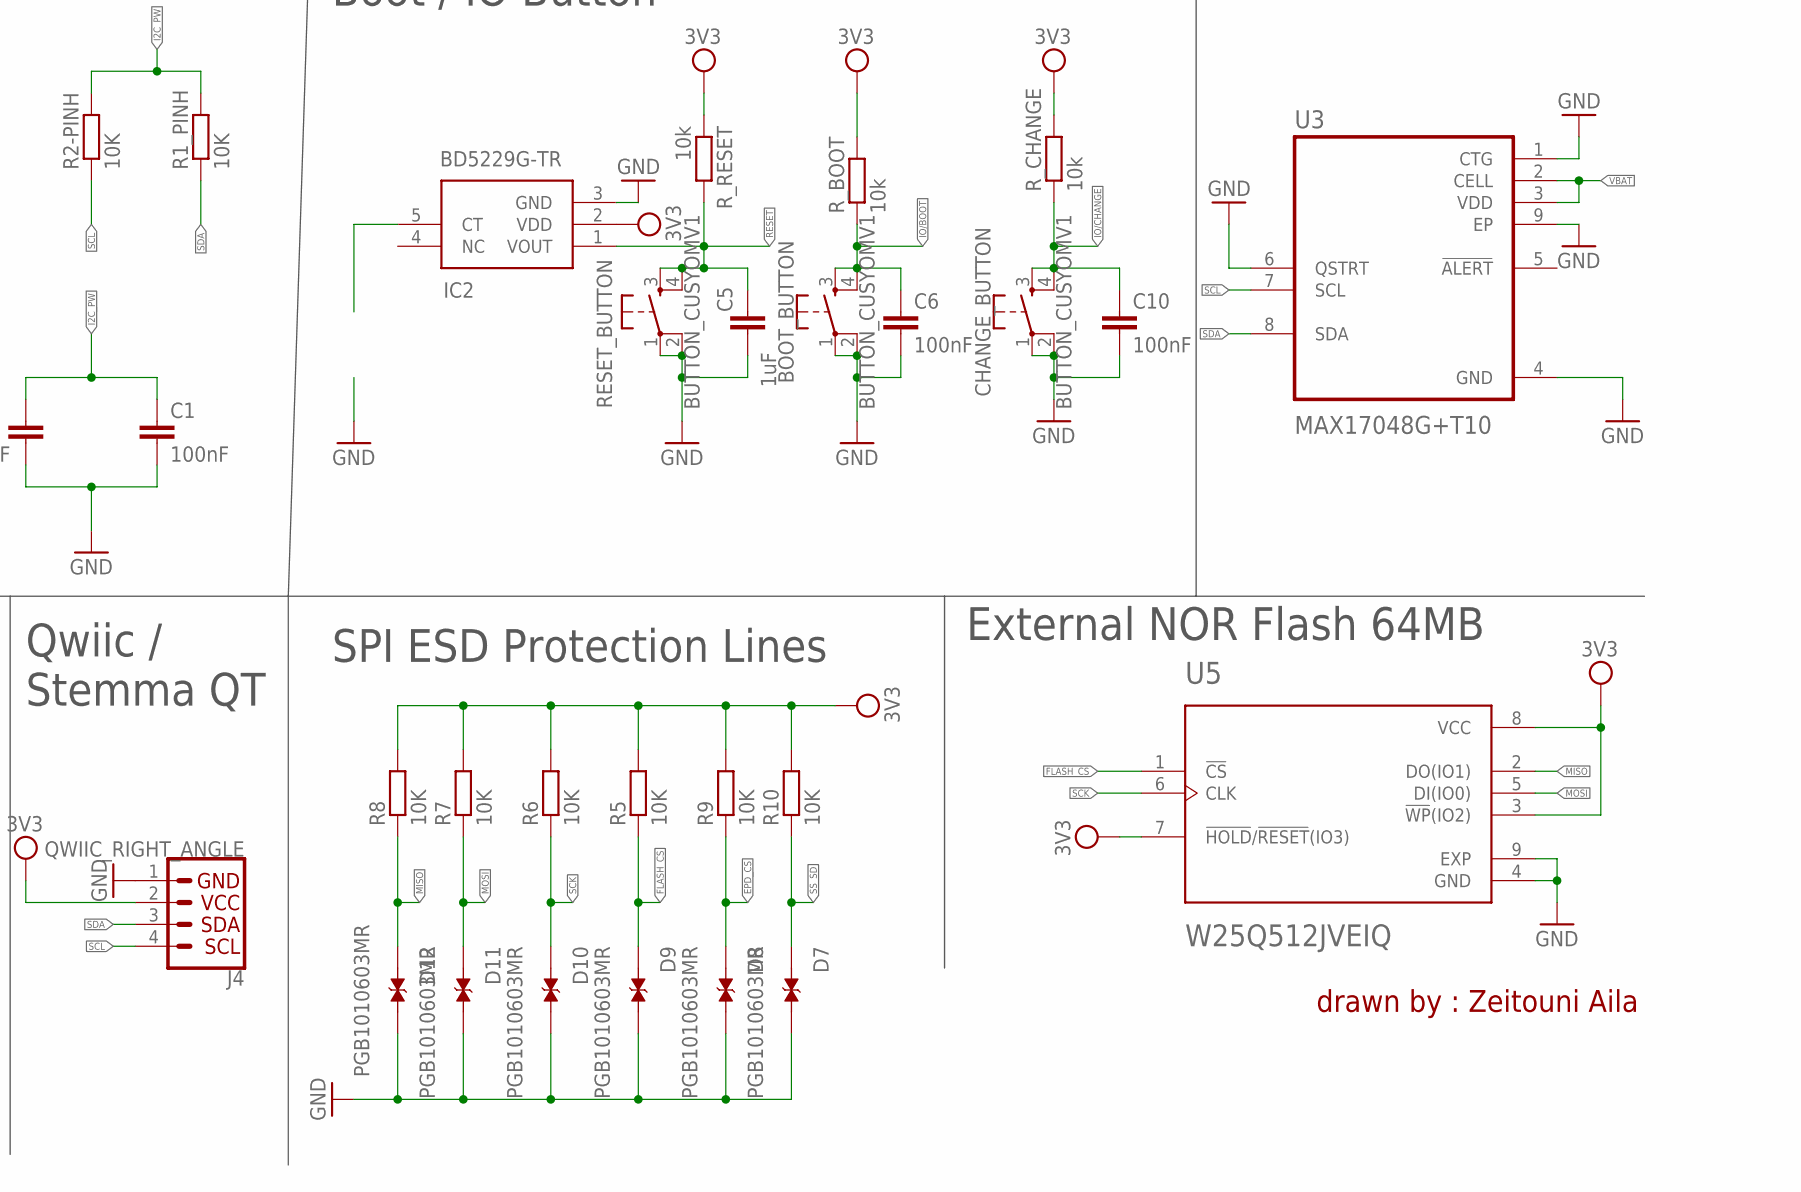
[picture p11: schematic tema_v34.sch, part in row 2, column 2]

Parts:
BOOT_BUTTON: BUTTON_CUSYOMV1; MYBUTTON
C1, C2, C4_USB, C6, C8, C9, C10: 100nF; ESP32_WROVER_EAGLE-LTSPICE_C0402
C1_BAT, C1_BAT1, C2_BAT, C5_USB: 4.7uF; ESP32_WROVER_EAGLE-LTSPICE_C0402
C1_BAT2: 4,7uF; ESP32_WROVER_EAGLE-LTSPICE_C0402
C3: 100uF TANT; RCL_CT3528
C4: 4.7uF/25V; ESP32_WROVER_EAGLE-LTSPICE_C0402
C5: 1uF; ESP32_WROVER_EAGLE-LTSPICE_C0402
C7: 10uF; ESP32_WROVER_EAGLE-LTSPICE_C0402
C10_SUPERCAP: CPH3225A; CAPCP3225X100N
CHANGE_BUTTON: BUTTON_CUSYOMV1; MYBUTTON
CHG_LED: ADAFRUIT_LEDCHIP-LED0603; ADAFRUIT_CHIP-LED0603
D1: USBLC6-2SC6Y; SOT95P280X145-6N
D2, D6: ESP32_WROVER_AVX---SD0805S020S1R0_AVX_SD0805S020S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; SOT95P280X120-5N
D3, D4, D5: MBR0530; SOD3716X135N
D7, D8, D9, D10, D11, D12: PGB1010603MR; DIOC1608X36N
EPD_C1, EPD_C2, EPD_C5, EPD_C6, EPD_C7, EPD_C8, EPD_C9, EPD_C10, EPD_C11, EPD_C12: 1uF/50V; ESP32_WROVER_EAGLE-LTSPICE_C0402
IC1: XC6220A331MR-G; SOT95P280X120-5N
IC2: BD5229G-TR; SOT95P280X120-5N
J1: SAMACSYS_PARTS_USB4110-GF-A; SAMACSYS_PARTS_USB4110GFA
J2: 112A-TAAR-R03_ATTEND; 112ATAARR03ATTEND
J3: FH34SRJ-24S-0.5SH_99_; FH34SRJ24S05SH99
J4: QWIIC_RIGHT_ANGLE; JST04_1MM_RA
L1: 68uH; IND_4828-WE-TPC_WRE
PFMF.050.1: ESP32C6_VARISTORCN1812; ESP32C6_VARISTOR_CT/CN1812
Q1, Q2: 20V/4.2A/52mΩ/1.4W; ESP32_WROVER_SPARKFUN-IC-POWER_SOT23-5
Q3: SI1308EDL-T1-GE3; SOT65P210X110-3N
R1, R1_PINH, R1_PINH1, R2-PINH, R2_PINH1, R4, R5, R6, R7, R8, R9, R10: 10K; ESP32_WROVER_EAGLE-LTSPICE_R0402
R1_BAT: 200; ESP32_WROVER_EAGLE-LTSPICE_R0402
R1_PWRUSB: 100K; ESP32_WROVER_EAGLE-LTSPICE_R0402
R2: 2.2; ESP32_WROVER_EAGLE-LTSPICE_R0402
R2-USB1: 5k1; ESP32_WROVER_EAGLE-LTSPICE_R0402
R2_BAT: 2K; ESP32_WROVER_EAGLE-LTSPICE_R0402
R2_USB: 5K1; ESP32_WROVER_EAGLE-LTSPICE_R0402
R3: 0.47; ESP32_WROVER_EAGLE-LTSPICE_R0402
RESET_BUTTON: BUTTON_CUSYOMV1; MYBUTTON
R_BOOT: 10k; ESP32_WROVER_EAGLE-LTSPICE_R0402
R_CAPACITOR: 15; ESP32_WROVER_EAGLE-LTSPICE_R0402
R_CHANGE: 10k; ESP32_WROVER_EAGLE-LTSPICE_R0402
R_CL1: 10K; ESP32_WROVER_EAGLE-LTSPICE_R0402
R_RESET: 10k; ESP32_WROVER_EAGLE-LTSPICE_R0402
SENSOR2: ESP32_WROVER_BME680_BME680; ESP32_WROVER_BME680_PSON80P300X300X100-8N
SJ1: SJ
TP1, TP2, TP3, TP4, TP5, TP6, TP7, TP8, TP9, TP10, TP11, TP12, TP13, TP14, TP15, TP16, TP17: TPTP20R; TP20R
U1: ESP32_WROVER_SPARKFUN-IC-POWER_MCP73831; SOT95P280X125-5N
U2: ESP32-C6-WROOM-1-N8; XCVR_ESP32-C6-WROOM-1-N8
U3: MAX17048G+T10; SON50P200X200X80-9N
U4: DS3231SN#; SOIC127P1032X265-16N
U5: W25Q512JVEIQ; SON50P200X200X80-9N

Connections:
3V3: C1_BAT2.1, C3.+, C9.1, D6.2 (ANODE), IC1.5 (VOUT), IC2.2 (VDD), J2.P4 (VDD), J4.2, Q2.3 (D), R1.2, R1_PINH1.2, R2_PINH1.2, R5.2, R6.2, R7.2, R8.2, R9.2, R10.2, R_BOOT.2, R_CHANGE.2, R_CL1.2, R_RESET.1, TP16.TP, U2.2 (3V3), U4.2 (VCC), U5.3 (!WP!(IO2)), U5.7 (!HOLD!/!RESET!(IO3)), U5.8 (VCC)
32KHZ: R2_PINH1.1, U2.9 (IO1), U4.1 (32KHZ)
DN: D1.4 (I/O2_2), J1.A7, J1.B7
DP: D1.6 (I/O1_2), J1.A6, J1.B6
EPD_3V3: C7.1, J3.16, L1.2, Q2.2 (S), TP17.TP
EPD_3V3_C: Q2.1 (G), R_CL1.1, TP13.TP, U2.18 (IO20)
EPD_BUSY: J3.9, TP9.TP, U2.26 (IO3)
EPD_CS: D8.1, J3.12, R9.1, TP10.TP, U2.11 (IO10)
EPD_DC: J3.11, TP11.TP, U2.5 (IO5)
EPD_RST: J3.10, TP12.TP, U2.21 (IO23)
FLASH_CS: D9.1, R5.1, U2.12 (IO11), U5.1 (!CS)
GDR: J3.2, Q3.1 (G), R4.2
GND: BOOT_BUTTON.1, BOOT_BUTTON.2, C1.2, C1_BAT.2, C1_BAT1.2, C1_BAT2.2, C2.2, C2_BAT.2, C3.-, C4_USB.2, C5.2, C5_USB.2, C6.2, C7.2, C9.2, C10.2, CHANGE_BUTTON.1, CHANGE_BUTTON.2, D7.2, D8.2, D9.2, D10.2, D11.2, D12.2, EPD_C1.1, EPD_C2.1, EPD_C5.1, EPD_C6.1, EPD_C7.1, EPD_C8.1, EPD_C9.1, EPD_C10.1, EPD_C11.1, EPD_C12.1, IC1.2 (VSS), IC2.3 (GND), J1.A1, J1.A12, J1.B1, J1.B12, J1.MP1, J1.MP2, J1.MP3, J1.MP4, J2.G1 (GND_1), J2.G2 (GND_2), J2.G3 (GND_3), J2.G4 (GND_4), J2.P6 (VSS), J3.8, J3.17, J3.MP1, J3.MP2, J4.1, R1_PWRUSB.1, R2.1, R2-USB1.1, R2_BAT.1, R2_USB.2, R4.1, RESET_BUTTON.1, RESET_BUTTON.2, SENSOR2.1 (GND), SENSOR2.5 (SDO), SENSOR2.7 (GND), SJ1.1, TP4.TP, TP5.TP, U1.2 (VSS), U2.1 (GND), U2.28 (GND), U2.29_1 (GND), U2.29_2 (GND), U2.29_3 (GND), U2.29_4 (GND), U2.29_5 (GND), U2.29_6 (GND), U2.29_7 (GND), U2.29_8 (GND), U2.29_9 (GND), U3.1 (CTG), U3.4 (GND), U3.6 (QSTRT), U3.9 (EP), U4.13 (GND), U5.4 (GND), U5.9 (EXP)
GPIO8: R1.1, U2.10 (IO8)
I2C_PW: C1.1, C2.1, R1_PINH.2, R2-PINH.2, SENSOR2.2 (CSB), SENSOR2.6 (VDDIO), SENSOR2.8 (VDD), U2.17 (IO19)
INT_RTC: R1_PINH1.1, TP15.TP, U2.8 (IO0), U4.3 (SQW/!INT)
IO/BOOT: BOOT_BUTTON.3, BOOT_BUTTON.4, C6.1, R_BOOT.1, U2.15 (IO9)
IO/CHANGE: C10.1, CHANGE_BUTTON.3, CHANGE_BUTTON.4, R_CHANGE.1, U2.23 (IO15)
MISO: D12.1, J2.P7 (DAT0), R8.1, TP6.TP, U2.27 (IO2), U5.2 (DO(IO1))
MOSI: D11.1, J2.P3 (CMD), J3.14, R7.1, TP7.TP, U2.7 (IO7), U5.5 (DI(IO0))
unnamed: J1.B5, R2_USB.1
unnamed: C1_BAT1.1, D2.1 (CATHODE), IC1.1 (VIN), IC1.3 (CE)
unnamed: J1.A5, R2-USB1.2
unnamed: C4.1, D3.1 (K), D4.2 (A)
unnamed: R1_BAT.2, U1.1 (STAT)
unnamed: R2_BAT.2, U1.5 (PROG)
unnamed: EPD_C12.2, J3.24
unnamed: EPD_C2.2, J3.5
unnamed: CHG_LED.C, R1_BAT.1
unnamed: EPD_C10.2, J3.22
unnamed: EPD_C8.2, J3.20
unnamed: EPD_C7.2, J3.19
unnamed: EPD_C6.2, J3.18
unnamed: EPD_C5.2, J3.15
unnamed: D6.1 (CATHODE), R_CAPACITOR.1
unnamed: C8.2, C10_SUPERCAP.1
unnamed: EPD_C1.2, J3.4
PREVGH: EPD_C9.2, J3.21
PREVGL: D3.2 (A), D5.1 (K), EPD_C11.2, J3.23
RESE: J3.3, Q3.2 (S), R2.2, R3.2, SJ1.2
RESE': R3.1
RESET: C5.1, IC2.1 (VOUT), RESET_BUTTON.3, RESET_BUTTON.4, R_RESET.2, U2.3 (EN)
RTC_RST: U2.16 (IO18), U4.4 (!RST)
RX: TP2.TP, U2.24 (RXD0/GPIO17)
SCK: D10.1, J2.P5 (CLK), J3.13, R6.1, TP8.TP, U2.6 (IO6), U5.6 (CLK)
SCL: J4.4, R2-PINH.1, SENSOR2.4 (SCK), U2.20 (IO22), U3.7 (SCL), U4.16 (SCL)
SDA: J4.3, R1_PINH.1, SENSOR2.3 (SDI), U2.19 (IO21), U3.8 (SDA), U4.15 (SDA)
SRC: C4.2, D5.2 (A), L1.1, Q3.3 (D)
SS_SD: D7.1, J2.P2 (CD/DAT3), R10.1, U2.4 (IO4)
TX: TP1.TP, U2.25 (TXD0/GPIO16)
USB_D+: D1.1 (I/O1_1), U2.14 (IO13)
USB_D-: D1.3 (I/O2_1), U2.13 (IO12)
VBAT: C2_BAT.1, Q1.3 (D), TP3.TP, U1.3 (VBAT), U3.2 (CELL), U3.3 (VDD)
VBUS: C1_BAT.1, C4_USB.1, C5_USB.1, CHG_LED.A, D1.5 (VBUS), D2.2 (ANODE), PFMF.050.1.2, Q1.1 (G), R1_PWRUSB.2, TP14.TP, U1.4 (VIN)
VRTC: C8.1, C10_SUPERCAP.2, R_CAPACITOR.2, U4.14 (VBAT)
VUSB: J1.A4, J1.A9, J1.B4, J1.B9, PFMF.050.1.1

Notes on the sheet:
USB C connector & ESD protection
LDO Voltage Regulator
SD Card
Display Type Selector
E-Paper Drive Circuit
Li-Po Battery Charging Controller
ESP32 C6
E-Paper Display Header
EPD Power
Environmental Sensor BME688
Voltage supervisor + Reset & Boot / IO Button
Battery Charge Level
Battery Charge LevelRTC Module DS3231SN
Test Pads
Qwiic / Stemma QT
SPI ESD Protection Lines
External NOR Flash 64MB
drawn by : Zeitouni Aila

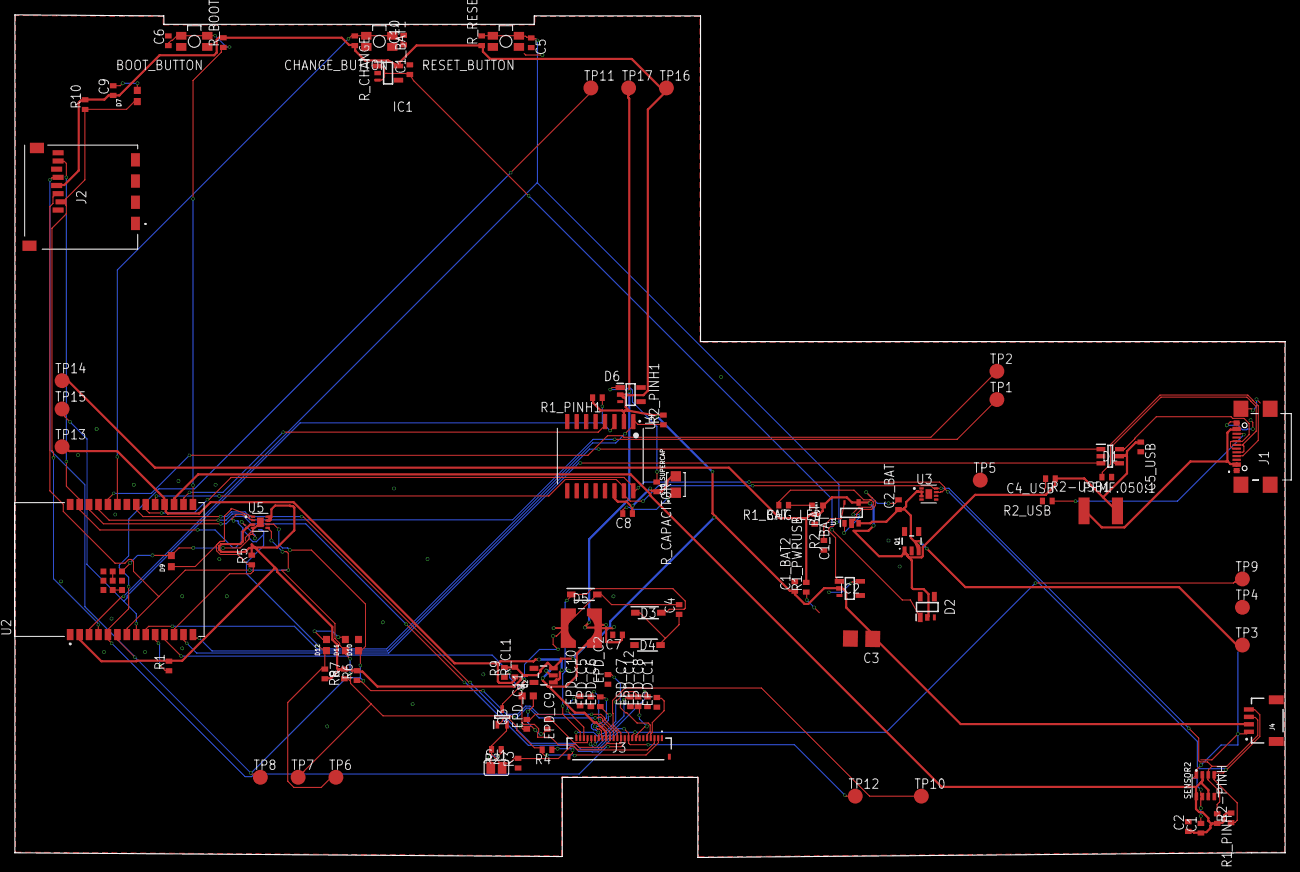
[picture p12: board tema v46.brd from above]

Board: 2 copper layers, 170.8 x 113.3 mm, 102 parts (0 on the bottom side), 55 nets.

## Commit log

2025-04-06 Initial commit with OpenBook hardware files
    [PickandPlace.csv, bom.csv, openbook.brd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]
2025-04-06 added readme.md
    [PickandPlace.csv]
2025-04-15 updated pickandplace
    [PickandPlace.csv]
2025-04-15 updated hardware
    [openbook1.brd, tema v46.brd, tema_v34.sch]
2025-04-15 updated 3d
    [bom.csv]

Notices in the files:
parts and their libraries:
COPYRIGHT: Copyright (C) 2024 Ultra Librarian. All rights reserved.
